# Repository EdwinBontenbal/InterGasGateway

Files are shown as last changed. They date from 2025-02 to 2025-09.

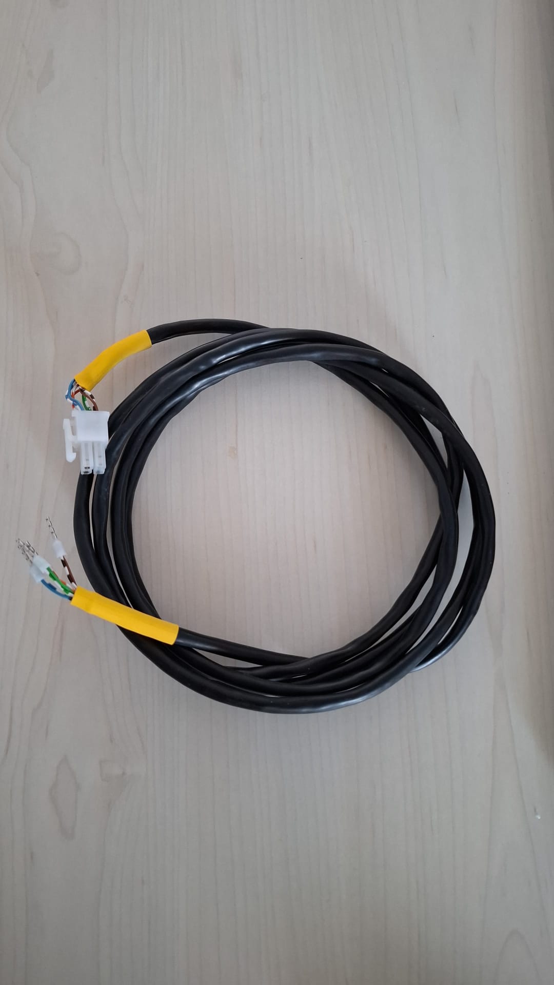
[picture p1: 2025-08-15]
Pictures/Completely Build Cable.jpg

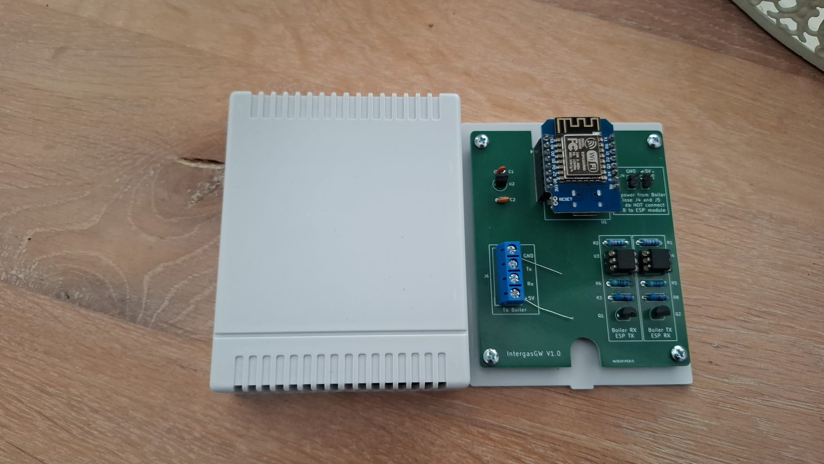
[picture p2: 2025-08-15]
Pictures/Completely Build.jpg

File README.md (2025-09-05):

# InterGasGateway
Arduino (esp8266) Hardware/Software to monitor a Intergas boiler over rs232 interface (x5) of the intergas boiler to Domotica Software with the use of MQTT.

# What to expect
This project consists of:
-  Hardware -> Cable diagram of between the IntergasGateway and the boiler
-  Hardware -> IntergasGateway Schemetic based on KiKad
-  Hardware -> IntergasGateway PCB based on KiKad
-  Software -> IntergasGateway sketch to be placed on arduino eps8266

# Hardware
A few requirements, set by myself, according to the hardware:
- Should be able to run paricitair on the boiler x5 PCB connector (without external power)
- High input RX/TX impedance
- RX/TX gavanically separated
- PCB should fitted in housing
- All parts can be ordered at Aliexpress
- PCb Easy to be ordered 
- Easy to build

# Software
A few requirements, set by myself, according to the software:
- Code should easy to read and logically setup
- Code should be expandable with ic3 burner
- Code should be based on statemachines
- Good serial debugging possibilities
- Output of retrieved data should be pushed to the serial port
- Output of retrieved data should be pushed to a mqtt listner (domotica software independent)
- Scheduled retrievel of data should be possible
- Reading the serial port should be fail save

# Usefull information
- When using the serial monitor function please set the speed to 115200
- The Gl_ParameterList als has a parameter to debug the serial port (ras data)

# Used tools
- Visual Studio code + platrformIO
- KiCad
- MQTT Explorer
- Python decompiler
- yed

# General requirements
- Based on opensource
- Robust
- Well documented
- Low cost
- Components easy to find and easy to order
- Reproducable

# Good to know
- Intergas has it's own software (IDS) for monitoring the X5 port of the boiler. You can download the original software at this link (https://www.intergas-verwarming.nl/zakelijk/download-ids-software/). The only thing you have to do is registrer yourself. The software was extremly usefull during the development of the arduino software.

# Help needed
I own a intergas boiler of type ic2 so I was able to develop the arduino parse code for the ic2 telegrams. I want to add and test also the ic3 telegrams therefor I need someone to test for me the arduino code. 

# Link to get the board
<a href="https://www.pcbway.com/project/shareproject/InterGasGW_Gateway_b01efd45.html">PCB from PCBWay</a>

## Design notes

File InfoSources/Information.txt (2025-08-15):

Interesting inks:

CircuitsOnline.net									GeneralInfo	Decoding messages	Schematics	Esp8266		Py
	https://www.circuitsonline.net/forum/view/80667					X

GitHub.com
https://github.com/HilcoTalen/RaspberryPI								X							X
https://github.com/So871/intergasHrE-esphome-reader							X					X
https://github.com/RichieB2B/intergas-exporter															X
https://github.com/rixvet/IntergasBoilerReader															X
https://github.com/keesma/Central-Heating-Intergas-Reader													X
https://github.com/keesma/Intergas-Central-Heating-Monitor-Homie/tree/master							X
https://github.com/Meewis/ESP8266_MQTT_INTERGAS						X		X					x			
https://github.com/jbouwh/incomfort-client/tree/master					X		X							X

Tweakers.net
	https://gathering.tweakers.net/forum/list_messages/2056344					X

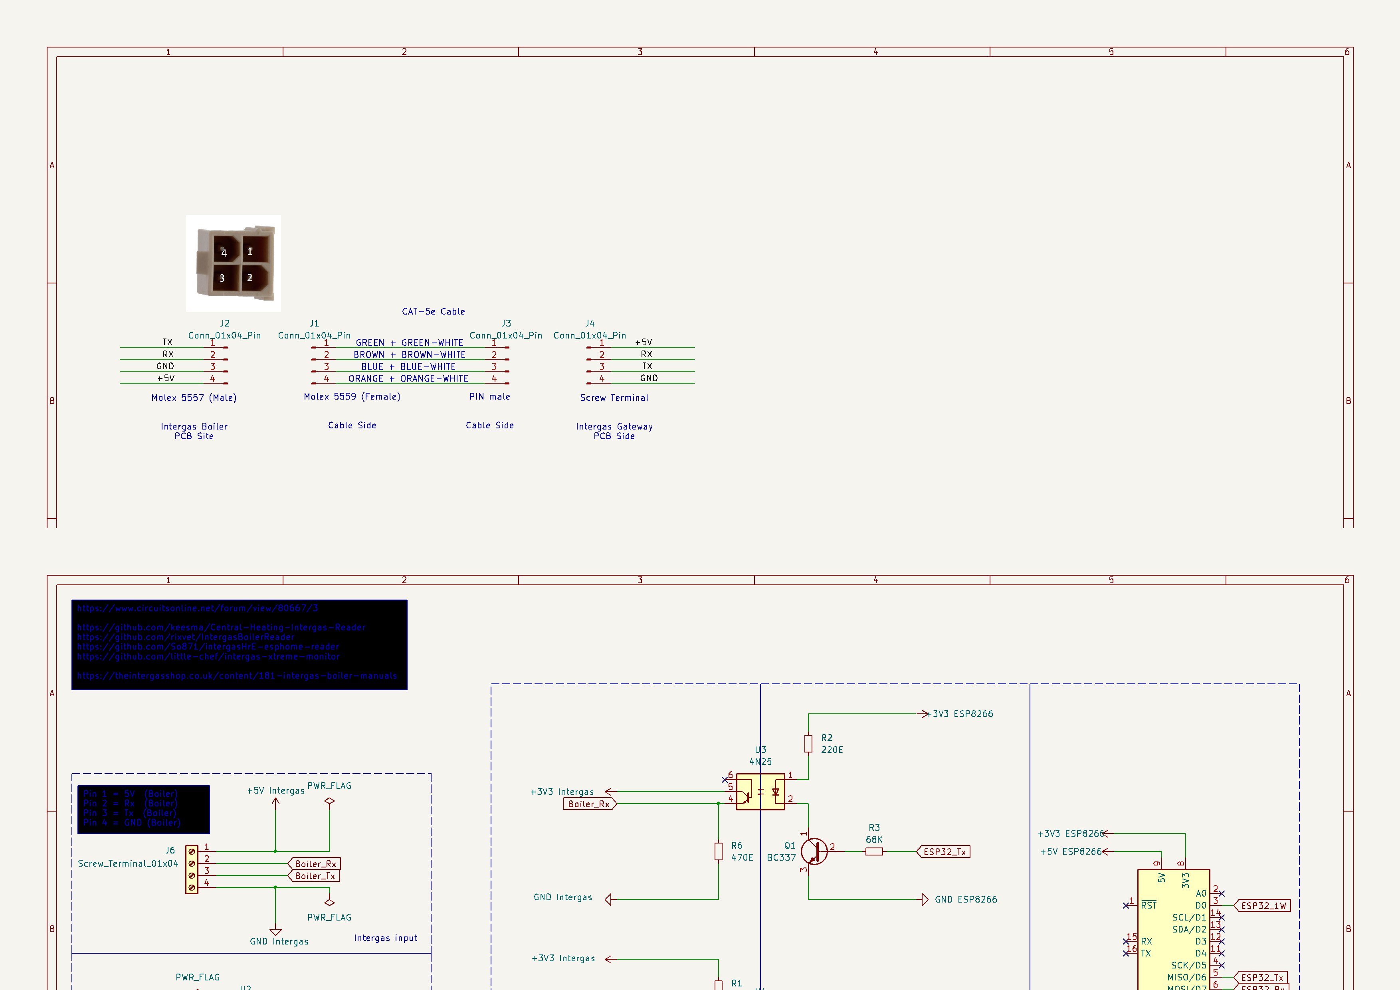
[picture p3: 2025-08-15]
Schematics/IntergasSchematic.png

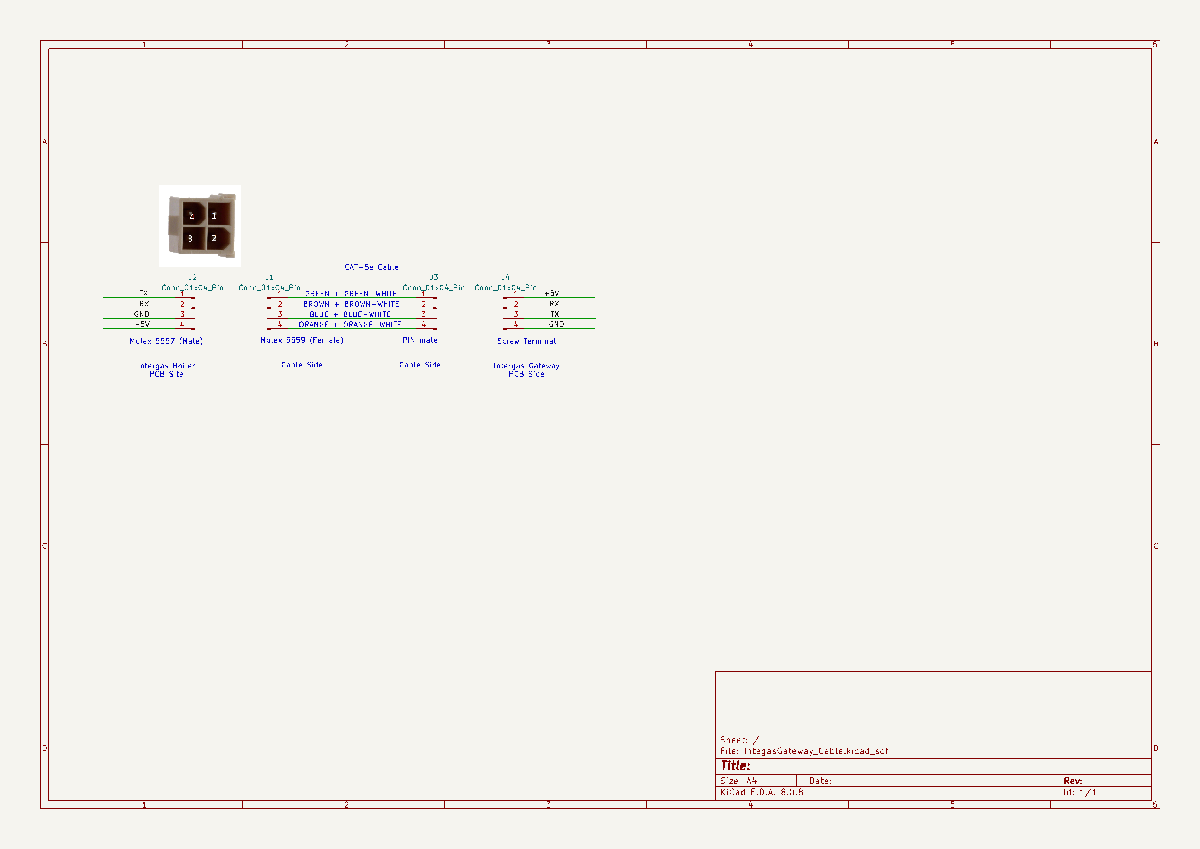
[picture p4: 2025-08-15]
Schematics/IntergasCable.png

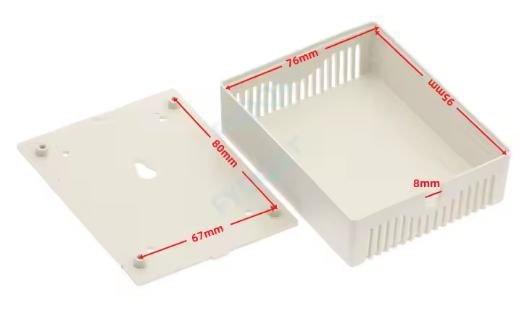
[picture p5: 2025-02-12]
Pictures/CasingDimensions.PNG

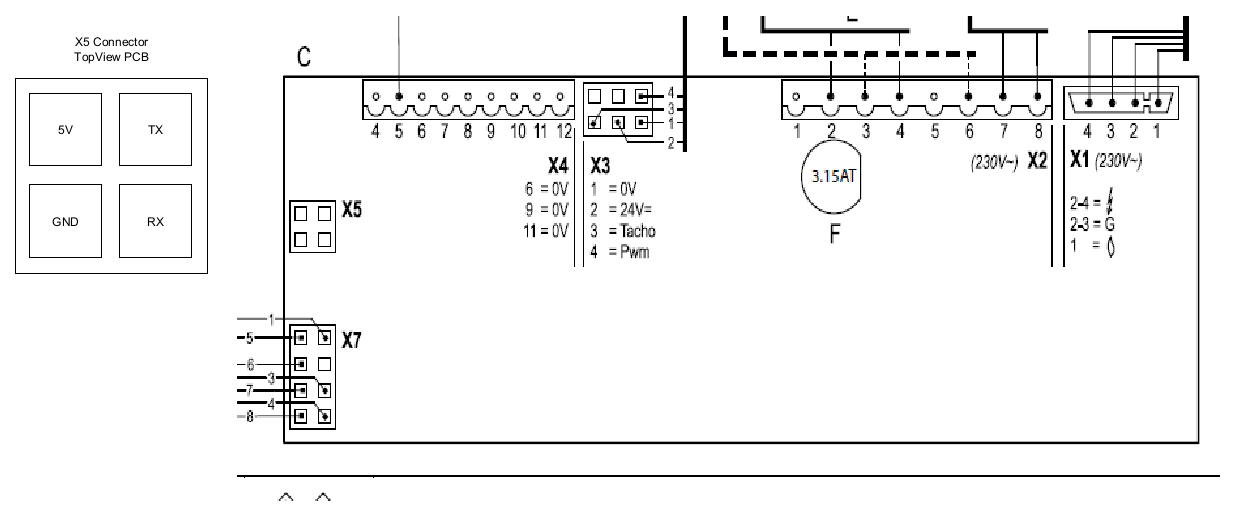
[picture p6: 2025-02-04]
Pictures/Intergas_Mainboard.bmp

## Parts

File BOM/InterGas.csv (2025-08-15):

Id | Designator | Footprint | Quantity | Designation | Supplier and ref
1 | J4,J5 | PinHeader_1x02_P2.54mm_Vertical | 2 | Conn_01x02_Pin
2 | U2 | TO-92L | 1 | L78L33_TO92
3 | Q2,Q1 | TO-92L | 2 | BC337
4 | R3,R6,R2,R5,R1,R8 | R_Axial_DIN0207_L6.3mm_D2.5mm_P7.62mm_Horizontal | 6 | 1K
5 | J6 | Altech_AK100_1x04_P5.00mm | 1 | Screw_Terminal_01x04
6 | U4,U3 | DIP-6_W7.62mm | 2 | 4N25
7 | C1 | C_Disc_D3.0mm_W1.6mm_P2.50mm | 1 | 10nF
8 | C2 | C_Disc_D3.0mm_W1.6mm_P2.50mm | 1 | 100nF
9 | U1 | WEMOS_D1_mini_light | 1 | WEMOS_D1_mini
10 | HOUSING | 100x80x29mm DIY | 1
11 | CABLE | CAT5E CABLE | 1
12 | CONNECTOR | MOLEX 4P FEMALE 5557 4.2 mm | 1
12 | PIN CONNECTOR | FEMALE 5557 4.2 mm | 1

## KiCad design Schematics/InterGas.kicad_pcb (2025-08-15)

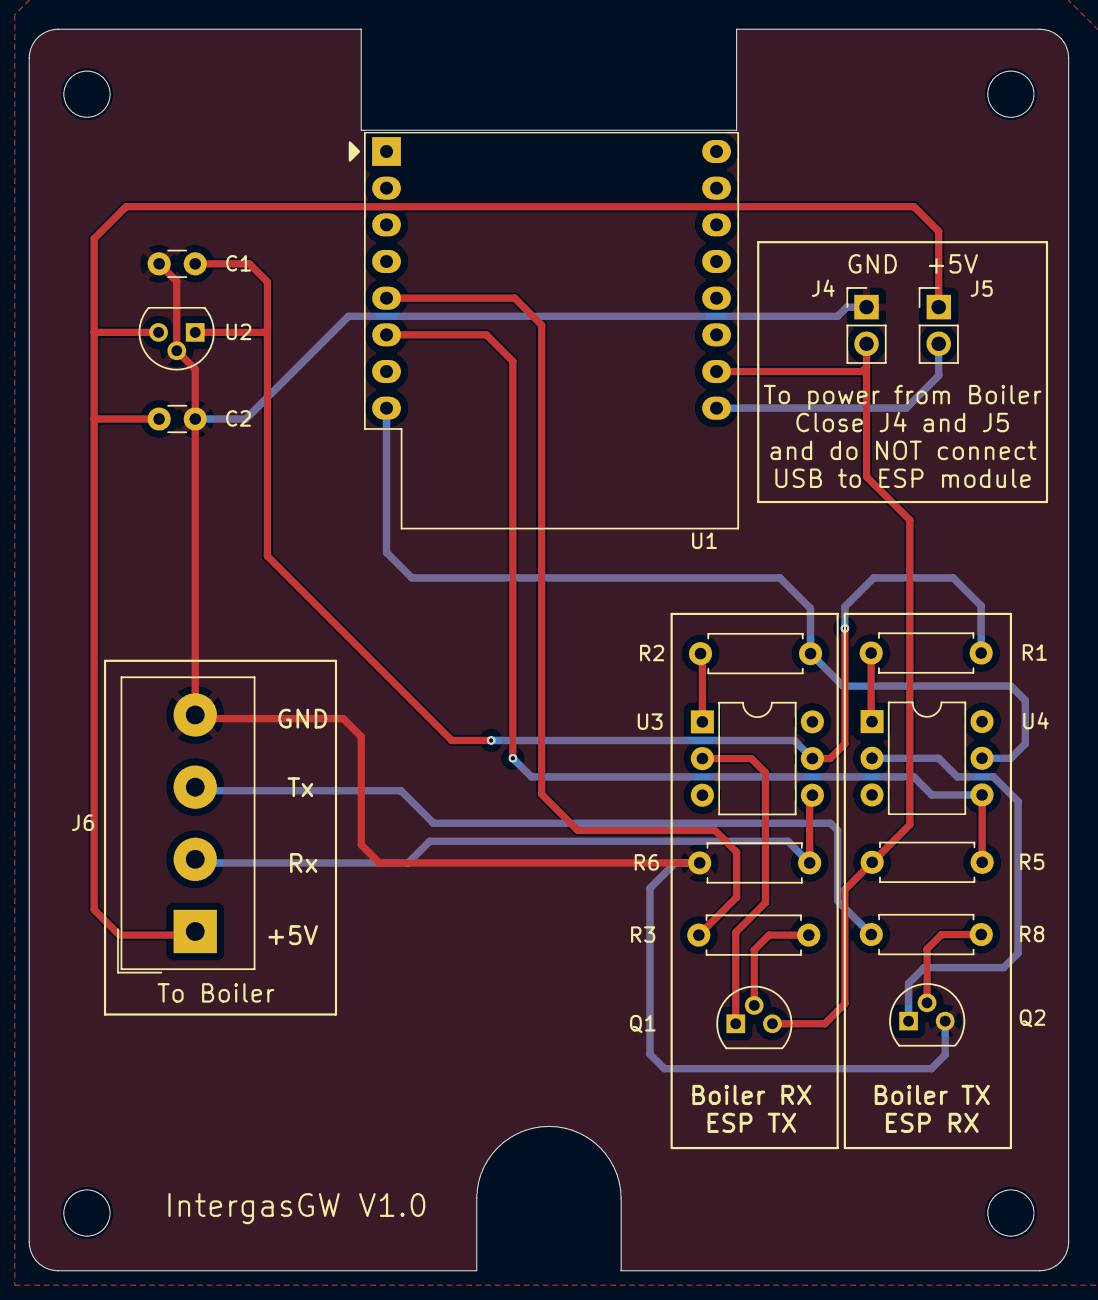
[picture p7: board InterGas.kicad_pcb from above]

Board: 2 copper layers, 72.0 x 86.0 mm, 21 parts (0 on the bottom side), 16 nets.

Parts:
C1: 10nF; C_Disc_D3.0mm_W1.6mm_P2.50mm
C2: 100nF; C_Disc_D3.0mm_W1.6mm_P2.50mm
H1, H2, H3, H4: MountingHole; MountingHole_3.2mm_M3
J4, J5: Conn_01x02_Pin; PinHeader_1x02_P2.54mm_Vertical
J6: Screw_Terminal_01x04; Altech_AK100_1x04_P5.00mm
Q1, Q2: BC337; TO-92L
R1, R2, R3, R5, R6, R8: 1K; R_Axial_DIN0207_L6.3mm_D2.5mm_P7.62mm_Horizontal
U1: WEMOS_D1_mini; WEMOS_D1_mini_light
U2: L78L33_TO92; TO-92L
U3, U4: 4N25; DIP-6_W7.62mm

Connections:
+3V3 ESP8266: R2.2, U1.8 (3V3), U4.5
+3V3 Intergas: C1.1, R1.2, U2.1 (VO), U3.5
+5V ESP8266: J5.2, U1.9 (5V)
+5V Intergas: C2.1, J5.1, J6.1, U2.3 (VI)
Boiler_Rx: J6.2, R6.2, U3.4
Boiler_Tx: J6.3, R8.1
ESP32_Rx: R5.2, U1.6 (MOSI/D7), U4.4
ESP32_Tx: R3.1, U1.5 (MISO/D6)
GND ESP8266: J4.2, Q1.3 (E), R5.1, U1.10 (GND)
GND Intergas: C1.2, C2.2, J4.1, J6.4, Q2.3 (E), R6.1, U2.2 (GND)
unnamed: Q1.2 (B), R3.2
unnamed: Q1.1 (C), U3.2
unnamed: Q2.2 (B), R8.2
unnamed: Q2.1 (C), U4.2
unnamed: R1.1, U4.1
unnamed: R2.1, U3.1

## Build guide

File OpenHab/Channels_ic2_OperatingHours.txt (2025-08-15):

  - id: OperatingHours_line_power_connected
    channelTypeUID: mqtt:number
    label: OperatingHours_line_power_connected
    configuration:
      stateTopic: InterGasGW/ic2_OperatingHours/line_power_connected
  - id: OperatingHours_line_power_disconnect
    channelTypeUID: mqtt:number
    label: OperatingHours_line_power_disconnect
    configuration:
      stateTopic: InterGasGW/ic2_OperatingHours/line_power_disconnect
  - id: OperatingHours_ch_function
    channelTypeUID: mqtt:number
    label: OperatingHours_ch_function
    configuration:
      stateTopic: InterGasGW/ic2_OperatingHours/ch_function
  - id: OperatingHours_dhw_function
    channelTypeUID: mqtt:number
    label: OperatingHours_dhw_function
    configuration:
      stateTopic: InterGasGW/ic2_OperatingHours/dhw_function
  - id: OperatingHours_burnerstarts
    channelTypeUID: mqtt:number
    label: OperatingHours_burnerstarts
    configuration:
      stateTopic: InterGasGW/ic2_OperatingHours/burnerstarts
  - id: OperatingHours_ignition_failed
    channelTypeUID: mqtt:number
    label: OperatingHours_ignition_failed
    configuration:
      stateTopic: InterGasGW/ic2_OperatingHours/ignition_failed
  - id: OperatingHours_flame_lost
    channelTypeUID: mqtt:number
    label: OperatingHours_flame_lost
    configuration:
      stateTopic: InterGasGW/ic2_OperatingHours/flame_lost
  - id: OperatingHours_reset
    channelTypeUID: mqtt:number
    label: OperatingHours_reset
    configuration:
      stateTopic: InterGasGW/ic2_OperatingHours/reset

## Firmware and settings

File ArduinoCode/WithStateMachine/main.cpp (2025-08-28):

#include <SoftwareSerial.h>
#include <ESP8266WiFi.h>
#include <PubSubClient.h>
#include <StateMachine.h>  
//
#include <EnvironmentSettings.h>
//
//Define Software Serial ports
#define Intergas_TXport                D6    // output to boiler
#define Intergas_RXport                D7    // input  to boiler
//
#define          ledPin                D4  
//
// Init Wifi Client and MQTT
WiFiClient   espClient;
PubSubClient client(espClient);
//
// Init staemachine
StateMachine IntergasStateMachine = StateMachine();
//
struct States {
  const char*           State;
};

struct States IGSMStates[25] = {
// 1234567890123456789012345678901 -> 31 + 1 char = 32
{ "IGSM_SetBurnerRequest"       		},
{ "IGSM_SendRequestToSerialPort1"		},
{ "IGSM_GetDataFromSerialPort1"	  	},
{ "IGSM_ParseDataFromSerialPort1"		},
{ "IGSM_SetBurnerSettings"	      	},
{ "IGSM_EmptySerialBuffer1"		      },
{ "IGSM_EmptySerialBuffer2"     		},
{ "IGSM_DetermineRequest"	        	},
{ "IGSM_SendRequestToSerialPort2"		},
{ "IGSM_GetDataFromSerialPort2"		  },
{ "IGSM_ParseDataFromSerialPort2"		},
{ "IGSM_PublishDataFromSerialPort1"	},
{ "IGSM_DisplayDataFromSerialPort1"	},
{ "IGSM_PublishDataFromSerialPort2"	},
{ "IGSM_DisplayDataFromSerialPort2"	},
{ "IGSM_PublishSerialStats"	      	}
};


#define Nothing                         0  // Build
#define ic2_Status                      1  // Build
#define StatusExtra                     2
#define ic2_BurnerVersion               3  // Build
#define ic2_Burner                      4  // Build
#define ic2_OperatingHours              5  // Build
#define ic2_Faults                      6  // Build
#define ic2_Parameters                  7  // Build
#define parametersExtra                 8
#define infoblok                        9
#define infoblokExtra                  10


struct TelegramObjects {
  const char*           Item;
  String                Formatted;
  const char*           Units;
  const char*           ExtraInfo;
};

struct TelegramObjects GL_ic2_Status[31] = {
  { "t1"                 , "" , "(  °C )", nullptr },
  { "t2"                 , "" , "(  °C )", nullptr },
  { "t3"                 , "" , "(  °C )", nullptr },
  { "t4"                 , "" , "(  °C )", nullptr },
  { "t5"                 , "" , "(  °C )", nullptr },
  { "t6"                 , "" , "(  °C )", nullptr },
  { "ch_pressure"        , "" , "( Bar )", nullptr },
  { "temp_set"           , "" , "(  °C )", nullptr },
  { "fanspeed_set"       , "" , "( RPM )", nullptr },
  { "fan_speed"          , "" , "( RPM )", nullptr },
  { "fan_pwm"            , "" , "( --- )", nullptr },
  { "io_curr"            , "" , "( --- )", nullptr },
  { "display_code"       , "" , "( --- )", nullptr },
  { "gp_switch"          , "" , "( --- )", nullptr },
  { "tap_switch"         , "" , "( --- )", nullptr },
  { "roomtherm"          , "" , "( --- )", nullptr },
  { "pump"               , "" , "( --- )", nullptr },
  { "dwk"                , "" , "( --- )", nullptr },
  { "alarm_status"       , "" , "( --- )", nullptr },
  { "ch_cascade_relay"   , "" , "( --- )", nullptr },
  { "opentherm"          , "" , "( --- )", nullptr },
  { "gasvalve"           , "" , "( --- )", nullptr },
  { "spark"              , "" , "( --- )", nullptr },
  { "io_signal"          , "" , "( --- )", nullptr },
  { "ch_ot_disabled"     , "" , "( --- )", nullptr },
  { "low_water_pressure" , "" , "( --- )", nullptr },
  { "pressure_sensor"    , "" , "( --- )", nullptr },
  { "burner_block"       , "" , "( --- )", nullptr },
  { "grad_flag"          , "" , "( --- )", nullptr }
};

struct TelegramObjects GL_ic2_Code[15] = {
  { "opentherm"               , "" , "( --- )" , nullptr },
  { "boiler_ext"              , "" , "( --- )" , nullptr },
  { "frost"                   , "" , "( --- )" , nullptr },
  { "central_heating_rf"      , "" , "( --- )" , nullptr },
  { "tapwater_int"            , "" , "( --- )" , nullptr },
  { "sensortest"              , "" , "( --- )" , nullptr },
  { "zone_heating"            , "" , "( --- )" , nullptr },
  { "standby"                 , "" , "( --- )" , nullptr },
  { "postrun_boiler"          , "" , "( --- )" , nullptr },
  { "service"                 , "" , "( --- )" , nullptr },
  { "tapwater"                , "" , "( --- )" , nullptr },
  { "postrun_ch"              , "" , "( --- )" , nullptr },
  { "boiler_int"              , "" , "( --- )" , nullptr },
  { "buffer"                  , "" , "( --- )" , nullptr },
};

struct TelegramObjects Gl_ic2_BurnerVersion[4] = {
  { "h_version"               , "" , "( --- )" , nullptr },
  { "s_version"               , "" , "( --- )" , nullptr },
  { "checksum1"               , "" , "( --- )" , nullptr },
  { "checksum2"               , "" , "( --- )" , nullptr },
};

struct TelegramObjects Gl_ic2_Burner[7] = {
  { "interrupt_time"          , "" , "( --- )" , nullptr },
  { "interrupt_load"          , "" , "(   % )" , nullptr },
  { "main_load"               , "" , "(   % )" , nullptr },
  { "net_frequency"           , "" , "(  Hz )" , nullptr },
  { "voltage_reference"       , "" , "(   V )" , nullptr },
  { "checksum1"               , "" , "( --- )" , nullptr },
  { "checksum2"               , "" , "( --- )" , nullptr },
};

struct TelegramObjects Gl_ic2_Faults[32] = {
  { "Fault00"                 , "" , "( --- )" , nullptr },
  { "Fault01"                 , "" , "( --- )" , nullptr },
  { "Fault02"                 , "" , "( --- )" , nullptr },
  { "Fault03"                 , "" , "( --- )" , nullptr },
  { "Fault04"                 , "" , "( --- )" , nullptr },
  { "Fault05"                 , "" , "( --- )" , nullptr },
  { "Fault06"                 , "" , "( --- )" , nullptr },
  { "Fault07"                 , "" , "( --- )" , nullptr },
  { "Fault08"                 , "" , "( --- )" , nullptr },
  { "Fault09"                 , "" , "( --- )" , nullptr },
  { "Fault10"                 , "" , "( --- )" , nullptr },
  { "Fault11"                 , "" , "( --- )" , nullptr },
  { "Fault12"                 , "" , "( --- )" , nullptr },
  { "Fault13"                 , "" , "( --- )" , nullptr },
  { "Fault14"                 , "" , "( --- )" , nullptr },
  { "Fault15"                 , "" , "( --- )" , nullptr },
  { "Fault16"                 , "" , "( --- )" , nullptr },
  { "Fault17"                 , "" , "( --- )" , nullptr },
  { "Fault18"                 , "" , "( --- )" , nullptr },
  { "Fault19"                 , "" , "( --- )" , nullptr },
  { "Fault20"                 , "" , "( --- )" , nullptr },
  { "Fault21"                 , "" , "( --- )" , nullptr },
  { "Fault22"                 , "" , "( --- )" , nullptr },
  { "Fault23"                 , "" , "( --- )" , nullptr },
  { "Fault24"                 , "" , "( --- )" , nullptr },
  { "Fault25"                 , "" , "( --- )" , nullptr },
  { "Fault26"                 , "" , "( --- )" , nullptr },
  { "Fault27"                 , "" , "( --- )" , nullptr },
  { "Fault28"                 , "" , "( --- )" , nullptr },
  { "Fault29"                 , "" , "( --- )" , nullptr },
  { "Fault30"                 , "" , "( --- )" , nullptr },
  { "Fault31"                 , "" , "( --- )" , nullptr },
};

struct TelegramObjects Gl_ic2_Parameters[30] = {
  { "heater_on"               , "" , "( --- )" , nullptr },
  { "comfort_mode"            , "" , "( --- )" , nullptr },
  { "ch_set_max"              , "" , "( --- )" , nullptr },
  { "dhw_set"                 , "" , "( --- )" , nullptr },
  { "eco_days"                , "" , "( --- )" , nullptr },
  { "comfort_set"             , "" , "( --- )" , nullptr },
  { "dhw_at_night"            , "" , "( --- )" , nullptr },
  { "ch_at_night"             , "" , "( --- )" , nullptr },
  { "param_1"                 , "" , "( --- )" , nullptr },
  { "param_2"                 , "" , "( --- )" , nullptr },
  { "param_3"                 , "" , "( --- )" , nullptr },
  { "param_4"                 , "" , "( --- )" , nullptr },
  { "param_5"                 , "" , "( --- )" , nullptr },
  { "param_6"                 , "" , "( --- )" , nullptr },
  { "param_7"                 , "" , "( --- )" , nullptr },
  { "param_8"                 , "" , "( --- )" , nullptr },
  { "param_9"                 , "" , "( --- )" , nullptr },
  { "param_A"                 , "" , "( --- )" , nullptr },
  { "param_b"                 , "" , "( --- )" , nullptr },
  { "param_C"                 , "" , "( --- )" , nullptr },
  { "param_d"                 , "" , "( --- )" , nullptr },
  { "param_E"                 , "" , "( --- )" , nullptr },
  { "param_E."                , "" , "( --- )" , nullptr },
  { "param_F"                 , "" , "( --- )" , nullptr },
  { "param_H"                 , "" , "( --- )" , nullptr },
  { "param_n"                 , "" , "( --- )" , nullptr },
  { "param_o"                 , "" , "( --- )" , nullptr },
  { "param_P"                 , "" , "( --- )" , nullptr },
  { "param_r"                 , "" , "( --- )" , nullptr },
  { "param_F."                , "" , "( --- )" , nullptr },
};

struct TelegramObjects Gl_ic2_OperatingHours[8] = {
  { "line_power_connected"    , "" , "(   h )" , nullptr },
  { "line_power_disconnect"   , "" , "(   # )" , nullptr },
  { "ch_function"             , "" , "(   h )" , nullptr },
  { "dhw_function"            , "" , "(   h )" , nullptr },
  { "burnerstarts"            , "" , "(   # )" , nullptr },
  { "ignition_failed"         , "" , "(   # )" , nullptr },
  { "flame_lost"              , "" , "(   # )" , nullptr },
  { "reset"                   , "" , "(   # )" , nullptr },
};

struct ParameterRecord {
  const byte            Telegram;
  const char*           SerialCommand;
  const bool            TelegramEnable;
  const bool            ic2;
  const bool            ic3;
  const bool            DebugSerialRxTx;
  const bool            WriteResultsToSerial;
  const bool            WriteResultsToMQTT;
  const byte            TelegramLength;
  const unsigned long   TelegramReadSchedule;
  const byte            TelegramMaxDuration;
  const char*           TelegramTypeName;
  unsigned long         TelegramLastTimeRun;
  bool                  TelegramValid;
  long                  TelegramErrors;
  int                   TelegramMaxRetrieveTime;
  int                   TelegramRetrieveTime;
}; 

const byte Gl_NoOfTelegrams = 11;   // N + 1 = 10 + 1 = 11

struct  ParameterRecord Gl_ParameterList[Gl_NoOfTelegrams] =
{
  {  0, ""       , false, true,  true, false, true,   true,  0,         0,     0, "Nothing"            , 0, 0, 0, 0, 0}, // Not used
  {  1, "S?\r"   ,  true, true, false, false, false,  true, 32,      1000,   155, "ic2_Status"         , 0, 0, 0, 0, 0}, // Max 150 ms, Prefered setting 160
  {  2, "S2\r"   , false,false, false, false, false, false, 32, 999999999,   155, "StatusExtra"        , 0, 0, 0, 0, 0}, // To be done
  {  3, "REV"    ,  true, true, false, false, false,  true, 32,   3600000,   155, "ic2_BurnerVersion"  , 0, 0, 0, 0, 0}, // Max 135 ms, Prefered setting 145
  {  4, "CRC"    ,  true, true, false, false, false,  true, 32,     60000,   155, "ic2_Burner"         , 0, 0, 0, 0, 0}, // Max 100 ms, Prefered setting 110
  {  5, "HN\r"   ,  true, true, false, false, false,  true, 32,     60000,   155, "ic2_OperatingHours" , 0, 0, 0, 0, 0}, // Max 130 ms, Prefered setting 140
  {  6, "EN\r"   ,  true, true, false, false, false,  true, 32,     10000,   155, "ic2_Faults"         , 0, 0, 0, 0, 0}, // Max 150 ms, Prefered setting 160
  {  7, "V?\r"   ,  true, true, false, false, false,  true, 32,     60000,   155, "ic2_Parameters"     , 0, 0, 0, 0, 0}, // Max 135 ms, Prefered setting 145
  {  8, "LX?"    , false,false, false, false, false, false, 32, 999999999,   155, "parametersExtra"    , 0, 0, 0, 0, 0}, // To be done
  {  9, "B?\r"   , false,false, false, false, false, false, 32, 999999999,   155, "infoblok"           , 0, 0, 0, 0, 0}, // To be done
  { 10, "B2\r"   , false,false, false, false, false, false, 32, 999999999,   155, "infoblokExtra"      , 0, 0, 0, 0, 0}  // To be done
};

const byte Gl_SerialRecieveTimeoutExtraDubugTime          = 200;

struct ic2_StatusResult{
  double t1;
  double t2;
  double t3;
  double t4;
  double t5;
  double t6;  
  double ch_pressure;
  double temp_set;
  double fanspeed_set;
  double fan_speed;
  double fan_pwm;
  double io_curr;
  double display_code;
  bool   gp_switch;
  bool   tap_switch;
  bool   roomtherm;
  bool   pump;
  bool   dwk;
  bool   alarm_status;
  bool   ch_cascade_relay;
  bool   opentherm;
  bool   gasvalve;
  bool   spark;
  bool   io_signal;
  bool   ch_ot_disabled;
  bool   low_water_pressure;
  bool   pressure_sensor;
  bool   burner_block;
  bool   grad_flag;
};

struct ic2_CodeResult{
  bool opentherm;
  bool boiler_ext;
  bool frost;
  bool central_heating_rf;
  bool tapwater_int;
  bool sensortest;
  bool zone_heating;
  bool standby;
  bool postrun_boiler;
  bool service;
  bool tapwater;
  bool postrun_ch;
  bool boiler_int;
  bool buffer;
};

struct ic2_BurnerVersionResult{
  char h_version[18];
  char s_version[6];
  int  checksum1; 
  int  checksum2;
};

struct ic2_BurnerResult{
  float interrupt_time;
  float interrupt_load;
  float main_load;
  float net_frequency;
  float voltage_reference;
  byte  checksum1;
  byte  checksum2;
};

struct ic2_OperatingHoursResult{
  int line_power_connected;
  int line_power_disconnect;
  int ch_function;
  int dhw_function;
  int burnerstarts;
  int ignition_failed;
  int flame_lost;
  int reset;
};

struct ic2_FaultsResult{
  byte  Fault00;
  byte  Fault01;
  byte  Fault02;
  byte  Fault03;
  byte  Fault04;
  byte  Fault05;
  byte  Fault06;
  byte  Fault07;
  byte  Fault08;
  byte  Fault09;
  byte  Fault10;
  byte  Fault11;
  byte  Fault12;
  byte  Fault13;
  byte  Fault14;
  byte  Fault15;
  byte  Fault16;
  byte  Fault17;
  byte  Fault18;
  byte  Fault19;
  byte  Fault20;
  byte  Fault21;
  byte  Fault22;
  byte  Fault23;
  byte  Fault24;
  byte  Fault25;
  byte  Fault26;
  byte  Fault27;
  byte  Fault28;
  byte  Fault29;
  byte  Fault30;
  byte  Fault31;
};

struct ic2_ParametersResult{
  byte heater_on;
  byte comfort_mode;
  byte ch_set_max;
  byte dhw_set;
  byte eco_days;
  byte comfort_set;
  byte dhw_at_night;
  byte ch_at_night;
  byte param_1;
  byte param_2;
  byte param_3;
  byte param_4;
  byte param_5;
  byte param_6;
  byte param_7;
  byte param_8;
  byte param_9;
  byte param_A;
  byte param_b;
  byte param_C;
  byte param_c;
  byte param_d;
  byte param_E;
  byte param_Edot;
  byte param_F;
  byte param_H;
  byte param_n;
  byte param_o;
  byte param_P;
  byte param_r;
  byte param_Fdot;
};

struct ic2_StatusResult             Gl_ic2_StatusResultNew;
struct ic2_StatusResult             Gl_ic2_StatusResultOld;
//
struct ic2_CodeResult               Gl_ic2_CodeResultNew;
struct ic2_CodeResult               Gl_ic2_CodeResultOld;
//
struct ic2_BurnerVersionResult      Gl_ic2_BurnerVersionResultNew;
struct ic2_BurnerVersionResult      Gl_ic2_BurnerVersionResultOld;
//
struct ic2_BurnerResult             Gl_ic2_BurnerResultNew;
struct ic2_BurnerResult             Gl_ic2_BurnerResultOld;
//
struct ic2_OperatingHoursResult     Gl_ic2_OperatingHoursResultNew;
struct ic2_OperatingHoursResult     Gl_ic2_OperatingHoursResultOld;
//
struct ic2_FaultsResult             Gl_ic2_FaultsResultNew;
struct ic2_FaultsResult             Gl_ic2_FaultsResultOld;
//
struct ic2_ParametersResult         Gl_ic2_ParametersResultNew;
struct ic2_ParametersResult         Gl_ic2_ParametersResultOld;

//

//Debug Parameters
bool          Gl_DebugState                           = true;

byte          Gl_Request                              = 0;

unsigned char Gl_RecievedArray[64];    

bool          Gl_ic2                                  = 0;
bool          Gl_ic3                                  = 0;

//Define Serial port
SoftwareSerial InterGasSerial(Intergas_RXport, Intergas_TXport); 

void MQTTconnect() {
  while (!client.connected()) {
    Serial.print        ("MQTT - Connecting MQTT   : ");
    //
    if (client.connect("ESP8266Client", mqtt_user, mqtt_password)) {
      Serial.println    ("Connected to MQTT");
      delay(500);
    }
    else {
      Serial.print      ("Error, rc=");
      Serial.println    (client.state());
      delay(500);
    }
  }
}


void SendMQTT(const char* loc_MQTTTopiclevel1, const char* loc_MQTTTopiclevel2, const char* loc_MQTTTopiclevel3, const char* loc_MQTTValue ) {
  char loc_MQTTTopic[200];
  //
  strcpy(loc_MQTTTopic, loc_MQTTTopiclevel1);
  strcat(loc_MQTTTopic, "/");
  strcat(loc_MQTTTopic, loc_MQTTTopiclevel2);
  strcat(loc_MQTTTopic, "/");
  strcat(loc_MQTTTopic, loc_MQTTTopiclevel3);
  //
  if (!client.connected()) {
    MQTTconnect();
  }
  //
  client.publish(loc_MQTTTopic, loc_MQTTValue);
}


void PrintTelegram (const char* loc_Topiclevel1, const char* loc_Topiclevel2, const char* loc_Topiclevel3, const char* loc_Value, const char* loc_Units){
  Serial.printf ("%-12s %-12s %-20s %10s %-10s \n", loc_Topiclevel1, loc_Topiclevel2, loc_Topiclevel3, loc_Value, loc_Units );
}


unsigned long Duration(unsigned long loc_time1, unsigned long loc_time2 ){ 
  //
  // Needed beacause roll-over of millis() (max 4294967295 ms)
  //
  // Example
  //
  //  loc_time1   loc_time1   Duration      
  // 4294917296  4294917296          0
  // 4294917297  4294917296          1
  // 4294917298  4294917296          2
  //     
  // 4294967295  4294917296      49999
  //          0  4294917296      50000
  //          1  4294917296      50001
  //
  //       9999  4294917296      59999
  //      10000  4294917296      60000
  //
  unsigned long loc_duration = 0;
  loc_duration = loc_time1 - loc_time2;
  return loc_duration;

}


double getDouble(byte msb, byte lsb) {
  // Combine msb and lsb into a signed 16-bit integer (for clarity)
  double value = (msb << 8) | lsb;  // Shift msb to the left and combine with lsb
  //
  // If the most significant bit of msb is set, the value is negative
  if (msb > 127) {
      value = value - 65536;  // Convert to negative by adjusting the range
  }
  //
  // Return the result scaled by 100
  return (double)value / 100.0;
}


int getInt(byte msb, byte lsb) {
    int loc_value;
    loc_value = int(msb * 256 + lsb);
  return loc_value;
}


int getSigned(byte lsb){
  int loc_Value;
  if (lsb > 127) {
      loc_Value = -int((lsb ^ 255) + 1);
  }
  else {
      loc_Value = lsb;
  }
  return loc_Value;
}


int Get_CRC(char byte1, char byte2, char byte3, char byte4) {
// Maak een lege string voor de CRC
String crc= "";

// Voor elke byte, converteer naar hex en zorg voor een lengte van 2 tekens
crc += String(byte1, HEX);
crc += String(byte2, HEX);
crc += String(byte3, HEX);
crc += String(byte4, HEX);

// Als de lengte van de hex-string één teken is, voeg dan een voorloopnul toe
crc.replace("0x", ""); // Verwijder de "0x" prefix die String(byte, HEX) toevoegt
while (crc.length() < 8) {
  crc = "0" + crc; // Voeg voorloopnullen toe tot de lengte 8 tekens is
}
return crc.toInt();
}


byte CheckFault (byte loc_FaultOccurences){
  //
  byte loc_Value = 0;
  //
  if (loc_FaultOccurences == 255) {
    loc_Value = 0;    
  }
  else {
    loc_Value = loc_FaultOccurences;
  }
  return loc_Value;
}


void WriteState() {
  if ( Gl_DebugState == true ) {
    Serial.printf     (  "State : %33s \n", IGSMStates[IntergasStateMachine.currentState].State );
  }
}


void SetBurnerRequest() {
  if ( IntergasStateMachine.executeOnce ) {
    WriteState();
  }
  //
  Gl_Request = ic2_BurnerVersion;
}


void SetBurnerSettings() {
  if ( IntergasStateMachine.executeOnce ) {
    WriteState();
  }
  //
  switch (Gl_ic2_BurnerVersionResultNew.h_version[2]){
    case '2':
      Serial.println     ( "Burner: Controller type IC2" );  
      Gl_ic2 = true;
      Gl_ic3 = false;
    break;
    case '3':
      Serial.println     ( "Burner: Controller type IC3" );  
      Gl_ic2 = false;
      Gl_ic3 = true;
    break;
  }
}


void EmptySerialBuffer() {
  unsigned long loc_Timer = 0;
  //
  if ( IntergasStateMachine.executeOnce ) {
    WriteState();
  }
  //
  do  
    while (InterGasSerial.available() > 0  ) {
      loc_Timer = millis() + 32;
      InterGasSerial.read();
    }
  while ((millis() < loc_Timer) );
}


void DetermineRequest () {
  //  
  if ( IntergasStateMachine.executeOnce ) {
    WriteState();
  }
  //
                Gl_Request  = 0;
  unsigned long CurrentTime = millis();
  //
  struct loc_ParameterRecord {
    bool                  TelegramEnable;
    bool                  ic2;
    bool                  ic3;
    unsigned long         OverTime;
  }; 
  //
  loc_ParameterRecord loc_ParameterList[Gl_NoOfTelegrams];
  //
  for (int counter = 1; counter < Gl_NoOfTelegrams; counter++) {
    loc_ParameterList[counter].TelegramEnable      = Gl_ParameterList[counter].TelegramEnable;
    loc_ParameterList[counter].ic2                 = Gl_ParameterList[counter].ic2;
    loc_ParameterList[counter].ic3                 = Gl_ParameterList[counter].ic3;
    //
    if (Duration(CurrentTime, Gl_ParameterList[counter].TelegramLastTimeRun) > Gl_ParameterList[counter].TelegramReadSchedule ) {
      loc_ParameterList[counter].OverTime     = (Duration(CurrentTime, Gl_ParameterList[counter].TelegramLastTimeRun) - Gl_ParameterList[counter].TelegramReadSchedule);
    }

    else {
      loc_ParameterList[counter].OverTime     = 0;
    }
  };
//
int             maxIndex = 0;
unsigned long   maxVal   = 0;

for (int counter = 1; counter < Gl_NoOfTelegrams; counter++) {
   if (  (loc_ParameterList[counter].TelegramEnable == true) and (loc_ParameterList[counter].ic2 == Gl_ic2) and (loc_ParameterList[counter].ic3 == Gl_ic3) and (loc_ParameterList[counter].OverTime > maxVal)) {
    maxVal   = loc_ParameterList[counter].OverTime;
    maxIndex = counter;
  }
}
//
Gl_Request = maxIndex;
}
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
void loop() {
  // Start the StateMachine
  IntergasStateMachine.run();
}

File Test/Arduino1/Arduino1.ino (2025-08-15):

#include <SoftwareSerial.h>// Import Software Serial library

#define Intergas_TX D6
#define Intergas_RX D7

SoftwareSerial InterGasSerial(Intergas_RX, Intergas_TX); // RX, TX

void setup() {
  // Open serial communications and wait for port to open:
  Serial        .begin(9600);
  InterGasSerial.begin(9600);
  
  while (!Serial) {
    ; // wait for serial port to connect. Needed for native USB port only
  }
  Serial.println(        "I am arduino 1");
}

void loop() { // run over and over
// Sent to port D6 D7
   InterGasSerial.print("Send from Arduino 1 to 2\r\n");
  
// Recieve to port D6 D7  
  while (InterGasSerial.available() > 0) {
    //Serial.println("readed");
    char inByte = InterGasSerial.read();
    Serial.print(inByte);
  }
  delay(1000);
}

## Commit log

2025-02-03 1st start schematics
    [InterGas.kicad_pcb, InterGas.kicad_sch]
2025-02-04 update
    update
    [IntegasGateway_Cable.kicad_pcb]
2025-02-12 Create CasingDimensions.PNG
    Added dimensions of the casing for PCB
2025-02-12 Create DrillHoles_PCB.png
    Drill holes for PCB
2025-04-06 OpenHab Files
    Openhab files for importing channel config
    [Channels_ic2_Parameters.txt]
2025-04-15 Update IntergasGateway__V0_9.ino
    Added reconnect function
    Added millis() rolover function
    Added duration of telegram
2025-08-15 Update Schematics
    [IntegasGateway_Cable.kicad_sch, InterGas.kicad_pcb, InterGas.kicad_sch]
2025-08-15 Added Schematics
    - cable
    - board
2025-08-28 Added burner id
    Added burner id in serial stream at startup
    [main.cpp]
